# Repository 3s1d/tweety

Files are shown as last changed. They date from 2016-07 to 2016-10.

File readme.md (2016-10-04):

# Skytraxx Tweety
A low-cost audio-only variometer which is fully open hardware/source and Arduino compatible.
It uses a [MS5637](http://www.mouser.com/new/measurement-specialties/measurement-specialties-ms5637/) pressure sensor in combination with [Linear Regression](https://en.wikipedia.org/wiki/Linear_regression) to estimate the current climb rate. All the computations are done on an Atmel [Attiny88](http://www.atmel.com/devices/ATTINY88.aspx). The CR2450 battery should last a whole season...

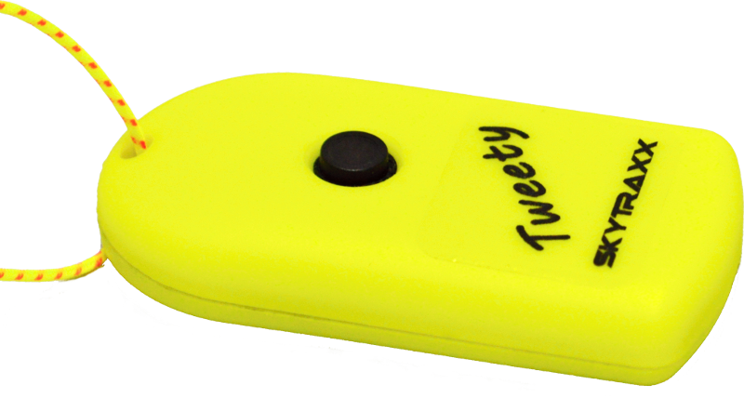
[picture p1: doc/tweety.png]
Tweety


You can build it on your own or buy it in our [shop](https://www.skytraxx.eu/shop?product_id=290) and modify it as you like.

## Operation

### Turn on
Press the button until you here a short beep. Release the button within in 1 second and Tweety turns on. You will here the welcome sound, followed by 0.5 sec pause and the battery state:
- 2 beeps: Battery is good
- 1 beep: Battery is okay
- no beep: You should consider changing the battery

### Turn off
Press the button until you hear the bye sound. Release the button.

### Auto-off
Tweety will shutdown itself if in the past 30 min all climb rate were within -0.8 m/s to 0.8 m/s.

### Configuration
The sink tone can be switched on or off.
Remove the battery. Press and hold the button while re-inserting the coin cell. Release the button. 
- 2 beeps: Sink tone on
- 1 beep: Sink tone off

A short press changes the settings. Use long press (4 sec.) to store the setting and to enter the normal operation mode again.

## Settings
See `climb.h`
- Climb threshold: > 0.3m/s
- Sink threshold: < -2.5m/s
- Averaging interval: 1.5 sec

If you want to change those settings or change the vario tone profile (`piezo.c`), you need to recompile and upload the sources.

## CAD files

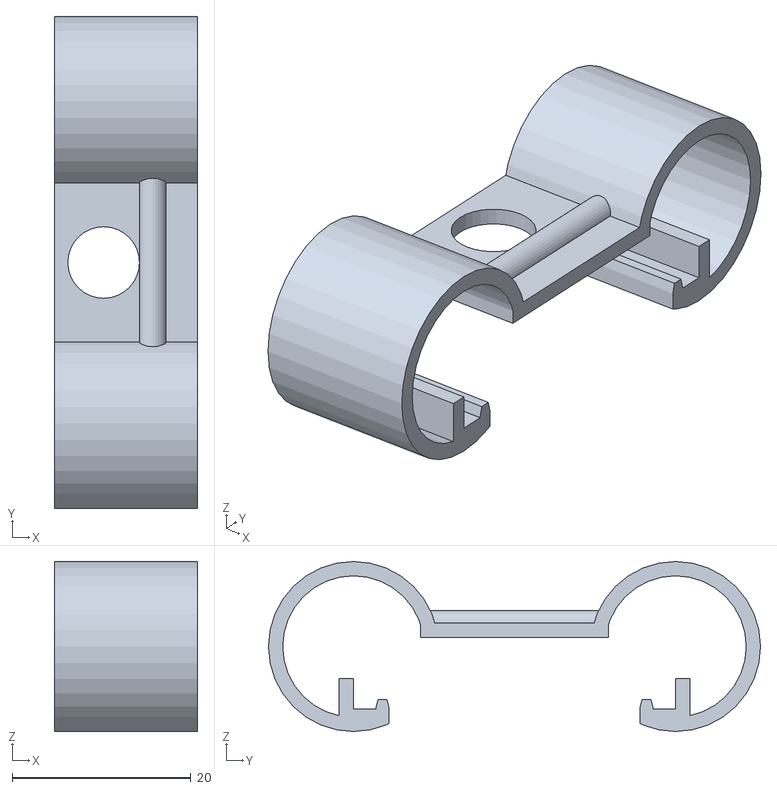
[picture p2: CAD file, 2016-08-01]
mount/clamp.stl
16.0 x 55.0 x 19.0

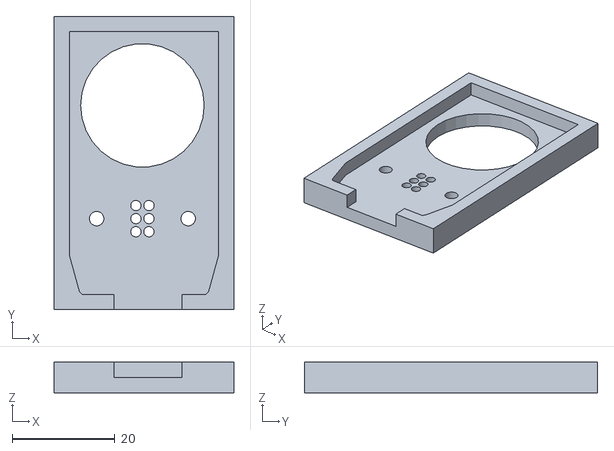
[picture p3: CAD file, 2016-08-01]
mount/base.stl
35.0 x 57.0 x 6.00

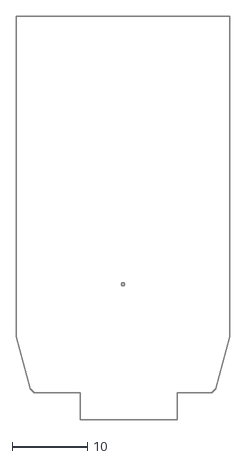
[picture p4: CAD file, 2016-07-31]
mount/tweety.dxf
28.4 x 53.6

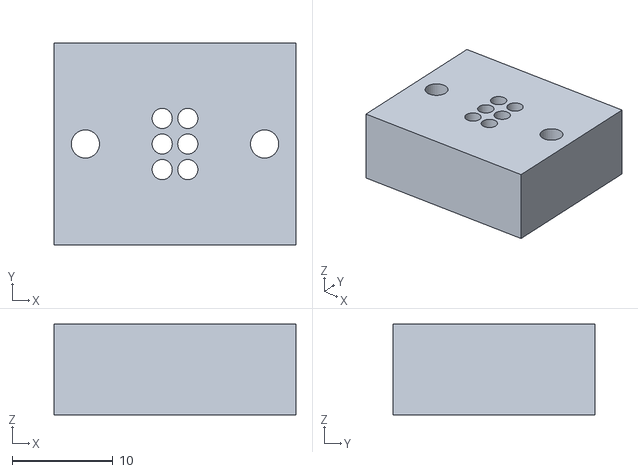
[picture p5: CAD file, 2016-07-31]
mount/base_support.stl
24.0 x 20.0 x 9.00

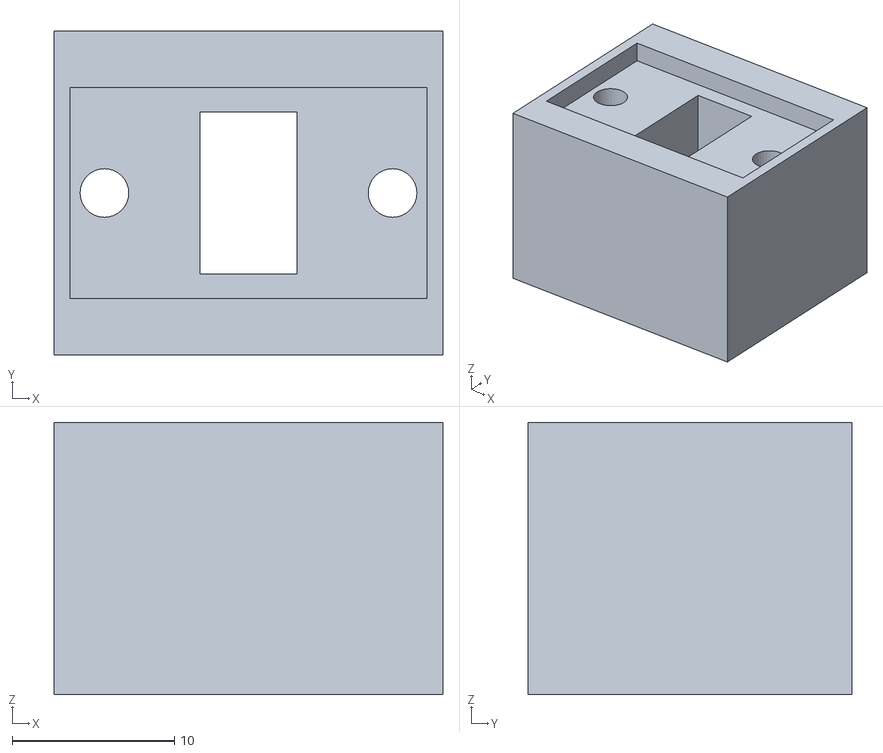
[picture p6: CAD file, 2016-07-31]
mount/base_support2.stl
24.0 x 20.0 x 16.8

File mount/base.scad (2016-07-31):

module pcb(scale = 1)
{
    scale([scale, scale, 1])
    {
        linear_extrude(height = 7)
           import(file = "tweety.dxf");
//        translate([26.3, 20.3, -20])
//            cylinder(r=0.1, h=30);   
    }
}

module isp(v)
{
    translate(v)
    {
        for(i=[-2.54:2.54:2.54])
        {
            translate([1.27,i,-10])
                cylinder(r=1, h=30, $fn=32);
            translate([-1.27,i,-10])
                cylinder(r=1, h=30, $fn=32);
        }
        
        
        translate([1.27 + 2.54*3, 0, -10])
            cylinder(r=2.8/2, h=30, $fn=32);

        translate([-1.27 - 2.54*3, 0, -10])
            cylinder(r=2.8/2, h=30, $fn=32);
    }
}

module clamp_mark(v)
{
    translate(v)
    {
        translate([14,-10,0])
            cube([2,20,1.5]);
        translate([-14-1.5,-10,0])
            cube([2,20,1.5]);        
    }
}

pcb_scale= 1.02;
isp_x = 26.3*pcb_scale;
isp_y = 20.3*pcb_scale;

module top()
{
    difference()
    {
        translate([12.4*pcb_scale-3, 5.9*pcb_scale-3, 0])
        cube([28.4*pcb_scale+2*3,50*pcb_scale+2*3, 6]);

        translate([0,0,3])
           pcb(pcb_scale);

        isp([isp_x, isp_y, 0]);
        clamp_mark([isp_x, isp_y, 0]);
        
        translate([isp_x, isp_y+22, 0])
            cylinder(r=12, h=10);
    }
}

module isp_support(v)
{
    translate(v)
    {
        difference()
        {
            translate([-24/2, -20/2, -9])
                cube([24, 20, 9]);
            isp();
        }
    }
}

module isp_support2(v)
{
    translate(v)
    {
        difference()
        {
            translate([-24/2, -20/2, 0])
                cube([24, 20, 15+1.8]);
 
            isp();           
            translate([-22/2, -13/2, 15])
                cube([22, 13, 1.8]);       
            translate([-6/2, -10/2, 0])
                cube([6, 10, 15+1.8]);
            
            translate([1.27 + 2.54*3, 0, -10])
                cylinder(r=3/2, h=30, $fn=32);

            translate([-1.27 - 2.54*3, 0, -10])
                cylinder(r=3/2, h=30, $fn=32);
        }
    }
}


top();
//isp_support([isp_x, isp_y, 0]);
//isp_support2([isp_x, isp_y, -15-9-1.8]);

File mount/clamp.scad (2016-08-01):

$fn=32;

module teeth(v)
{
    translate([0,-0.75, 0] + v)
    hull()
    {
        translate([0,0.25, 1])
            cube([16,1,0.1]);
        cube([16, 1.5, 0.1]);
    }
}

module clamp_half()
{
    difference()
    {
        union()
        {
            translate([0,28/2,0.4])
                cube([16,5.5, 1.6]);

            translate([0,18,0.4])
                cube([16, 1.6, 5]);

            translate([0,0,10])
                cube([16,10.5, 1.6]);

            teeth([0,29.5/2,2]);
            
            translate([0, 18, 9])
                rotate(90, [0,1,0])
                    difference()
                    {
                        cylinder(r=9.5, h=16);
                        cylinder(r=7.9, h=16);
                        translate([-1, -10, 0])
                            #cube([9,10,18]);
                        translate([-1, -14, 0])
                            #cube([12,10,18]);
                    }
                    
            translate([11, 0, 11.5])
                    rotate(90, [1,0,0])
                        cylinder(r=1.5, h=10);
       }
       translate([16/2-2-0.5, 0,0])
            cylinder(r=4, h=20);
    }
}

mirror([0,1,0])
    clamp_half();
clamp_half();

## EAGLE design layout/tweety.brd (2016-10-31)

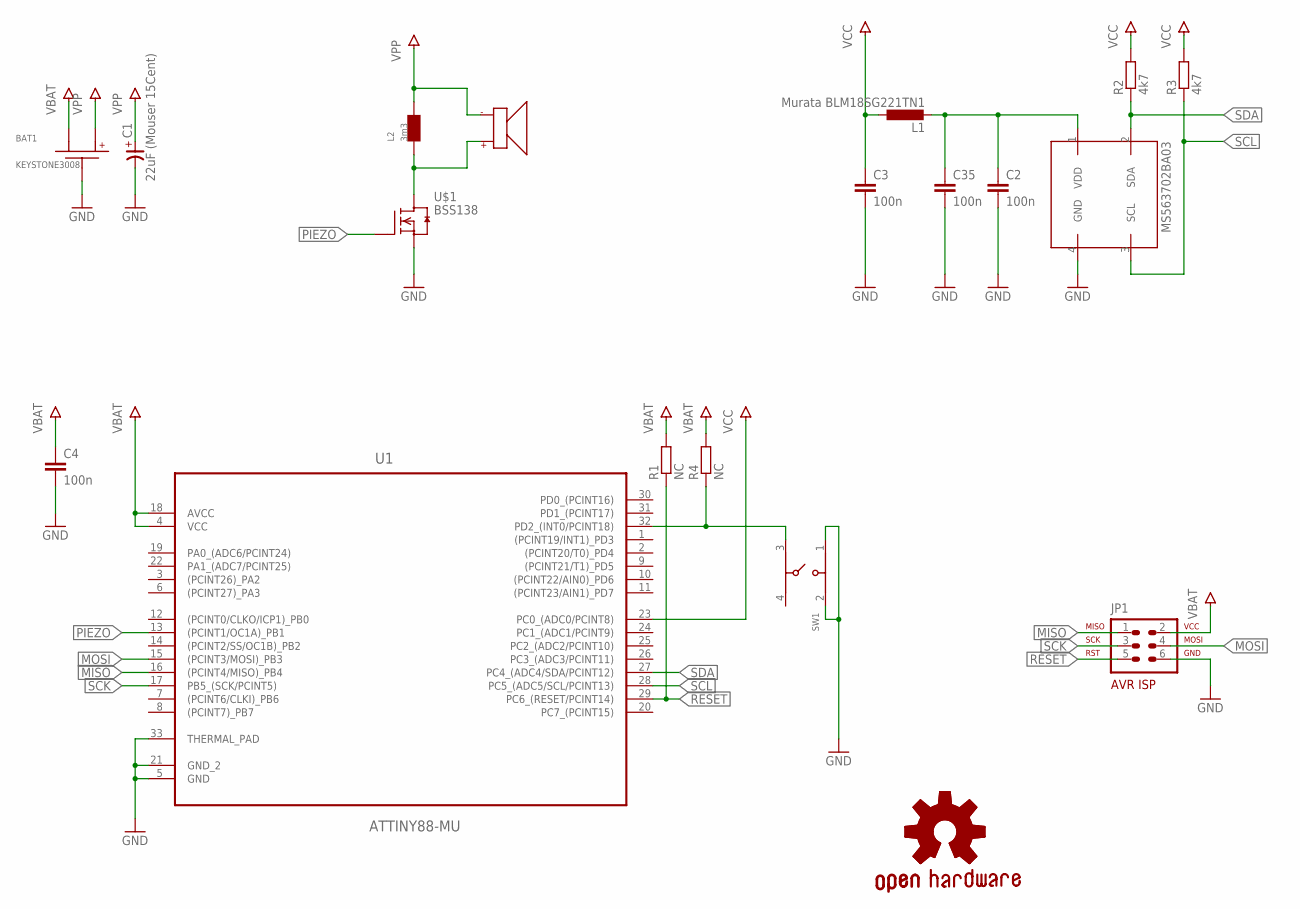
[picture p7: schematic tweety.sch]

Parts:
BAT1: KEYSTONE3008
C1: 22uF (Mouser 15Cent); 3528-21R/T
C2, C3, C4, C35: 100n; C0603
GOLD_ORB_SM1: OSHWLOGO_GOLD_ORB_MED; OSHW1
IC2: MS563702BA03; MS5637
JP1: AVR-ISP-6VERT; AVR-ISP-6
L1: Murata BLM18SG221TN1; L0603
L2: 3m3; SDR0503
P2: PKLCS1212E2400; PKLCS1212
R1, R4: NC; R0603
R2, R3: 4k7; R0603
SW1: 4301X20858X6
U1: ATTINY88-MU; QFN50P500X500X100-33N
U$1: BSS138; SOT23

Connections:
GND: BAT1.N, C1.-, C2.2, C3.2, C4.2, C35.2, IC2.4 (GND), JP1.6, SW1.1, SW1.2, U1.5 (GND), U1.21 (GND_2), U1.33 (THERMAL_PAD), U$1.2 (S)
MISO: JP1.1, U1.16 ((PCINT4/MISO)_PB4)
MOSI: JP1.4, U1.15 ((PCINT3/MOSI)_PB3)
unnamed: C2.1, C35.1, IC2.1 (VDD), L1.2
unnamed: R4.1, SW1.3, U1.32 (PD2_(INT0/PCINT18))
unnamed: L2.P$1, P2.P$+, U$1.3 (D)
PIEZO: U1.13 ((PCINT1/OC1A)_PB1), U$1.1 (G)
RESET: JP1.5, R1.1, U1.29 (PC6_(RESET/PCINT14))
SCK: JP1.3, U1.17 (PB5_(SCK/PCINT5))
SCL: IC2.3 (SCL), R3.1, U1.28 (PC5_(ADC5/SCL/PCINT13))
SDA: IC2.2 (SDA), R2.1, U1.27 (PC4_(ADC4/SDA/PCINT12))
VBAT: BAT1.P$3 (P1), C4.1, JP1.2, R1.2, R4.2, U1.4 (VCC), U1.18 (AVCC)
VCC: C3.1, L1.1, R2.2, R3.2, U1.23 (PC0_(ADC0/PCINT8))
VPP: BAT1.P$4 (P2), C1.+, L2.P$2, P2.P$-

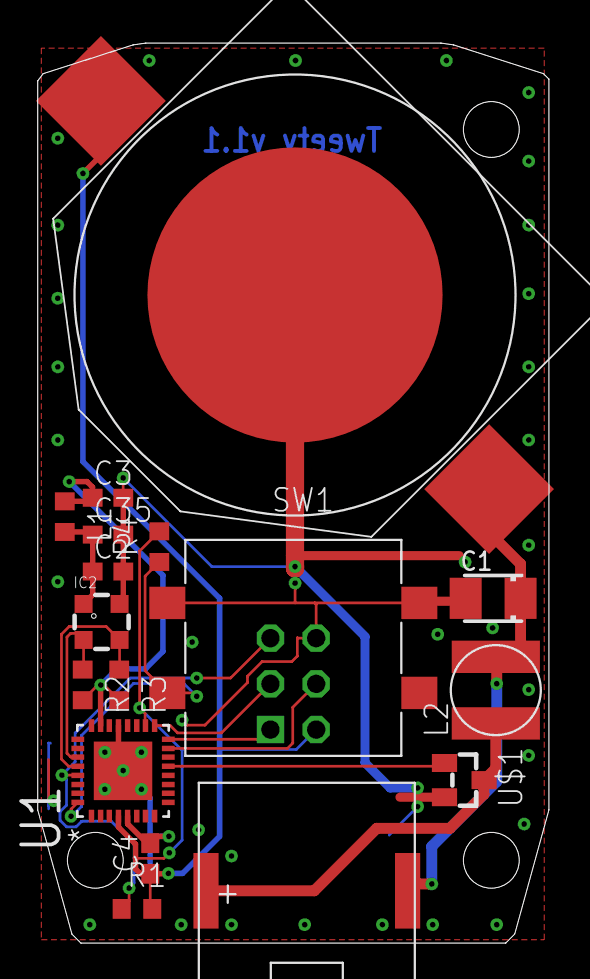
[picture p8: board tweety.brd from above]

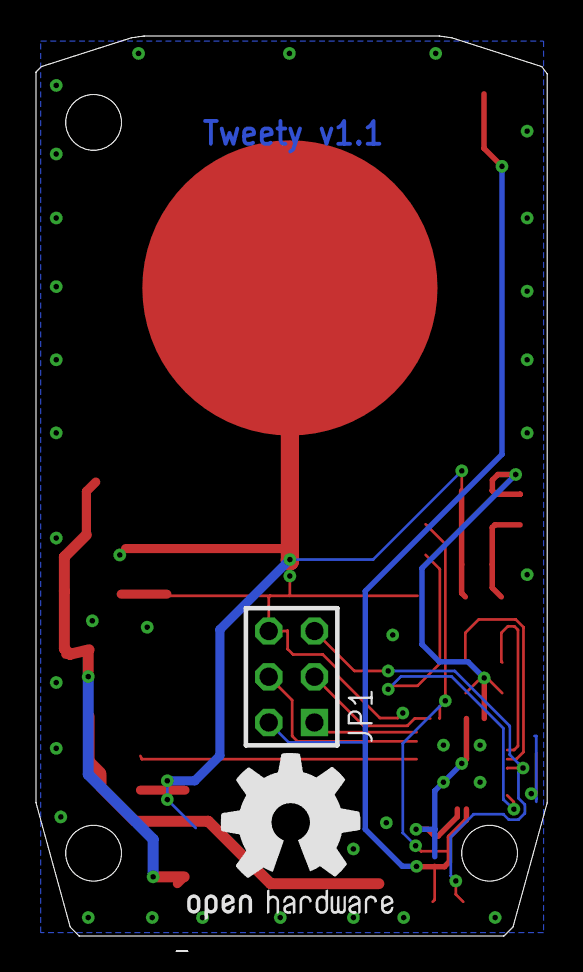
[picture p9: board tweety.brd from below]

Board: 2 copper layers, 28.4 x 50.0 mm, 19 parts (2 on the bottom side), 14 nets.

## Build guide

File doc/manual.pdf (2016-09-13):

⌛2 Sek.

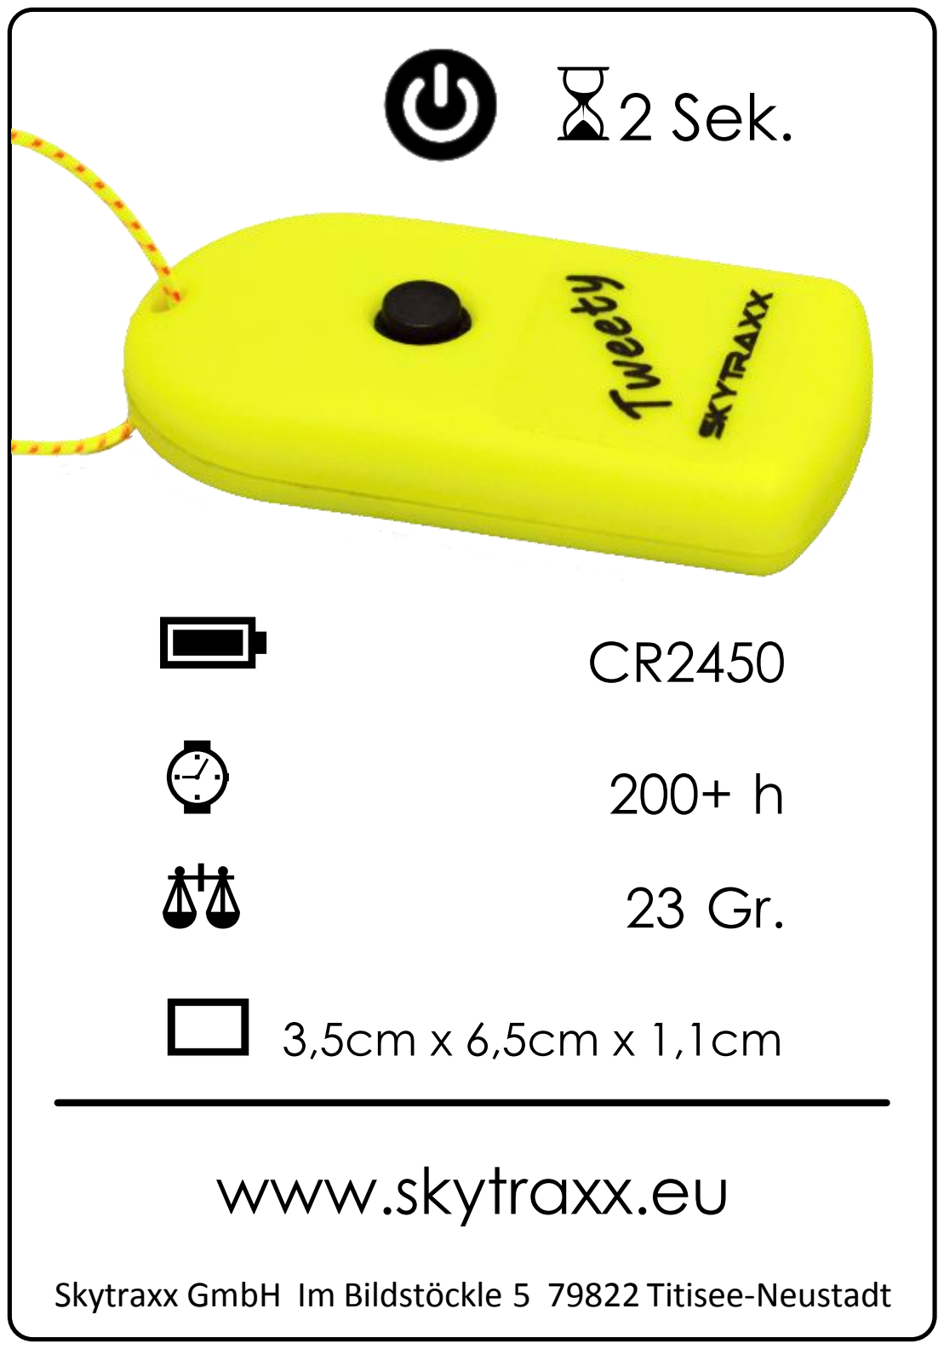
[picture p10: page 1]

🔋 | CR2450
⌚ | 200+ h
⚖ | 23 Gr.

### ▭ 3,5cm x 6,5cm x 1,1cm

## www.skytraxx.eu

Skytraxx GmbH Im Bildstöckle 5 79822 Titisee-Neustadt

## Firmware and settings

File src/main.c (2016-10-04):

/*
 * main.c
 *
 *  Created on: Jun 22, 2016
 *      Author: sid
 */

#include <avr/io.h>
#include <avr/interrupt.h>
#include <avr/power.h>
#include <util/delay.h>

#include "flexport.h"
#include "button.h"
#include "climb.h"
#include "piezo.h"
#include "sleep.h"
#include "main.h"

#include "debug.h"

volatile int t;

int main(void)
{
	/* enable pull-ups for all unused ports (reduces standby power) */
	//note: pins are already set as input
	PORTA = 0x0F;	//all ports
	PORTB = 0xFD;	//all except B,1 (piezo)
	PORTC = 0xCE;	//all except C,0 (ms5637 supply), C,4+5 (TWI)
	PORTD = 0xFF;	//all D,2 requires a pull-up anyway

	/* further reduce power consumption */
	power_spi_disable();
	power_adc_disable();

	/* Switch to 2Mhz */
	CLKPR = (1<<CLKPCE);
#if F_CPU == 2000000UL
	CLKPR = 2;		//div 4 -> 2Mhz
#elif F_CPU == 1000000UL
	//no need to change anything
#else
	#error adjust prescaler.
#endif

	/* Enable interrupts */
	sei();

	/* boot */
	btn_init();
	p_init();
	if(btn_pressed())
		p_config();
	climb_init();

	//debug_put(&p_dosink, 1);

	/* auto off */
	uint16_t idle_time = 0;

	/* button counter; instantaneously go into sleep mode @ power-up */
	uint8_t pressed = UINT8_MAX-1;

	while(1)
	{
		/* update climb rate */
		climb_update();

		/* check for flight condition */
		if((climb_cms < 80) && (climb_cms > -80))
			idle_time++;
		else
			idle_time = 0;

		//debug_put((uint8_t *) &climb_cms, sizeof(uint16_t));

		/* note: values heavily depends on F_CPU */
		/* also switch off about 30 minutes without climb or sink */
		if((pressed > 5) || (idle_time > MAINLOOP_HALFHOUR))
		{
			sleep();

			/* reset enter states */
			pressed = 0;
			idle_time = 0;
		}

		/* handle button */
		if(btn_pressed())
			pressed++;
		else
			pressed = 0;

	}
	return 1;
}

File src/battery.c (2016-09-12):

/*
 * battery.c
 *
 *  Created on: Aug 3, 2016
 *      Author: sid
 */

#include <avr/io.h>
#include <avr/power.h>
#include <util/delay.h>

//#include "debug.h"

uint8_t battery(uint8_t rep)
{
	/* turn on power */
	power_adc_enable();

	/* configure adc */
	ADMUX = _BV(REFS0) | _BV(ADLAR) | 0x0E;			//Vref=VCC | left adjusted | 1.1V channel
	ADCSRA = _BV(ADEN);
	//_delay_ms(1);						//minimum settle time

	/* taking the measurement */
	uint16_t bat = 0;
	for(uint8_t i=0; i<rep; i++)
	{
		_delay_ms(10);
		ADCSRA = _BV(ADEN) | _BV(ADSC) | (3<<ADPS0);		//div 8 (F_CPU=1MHz -> 125kHz Sample freq (recommended: 50-200kHz))
		while(ADCSRA&(1<<ADSC));
		bat += ADCH;
	}
	bat /= rep;

	/* cleanup */
	ADCSRA = 0;
	power_adc_disable();

	//uint8_t u = 2810/bat;
	//debug_put(&u, 1);

	/*
	 * Determine return value
	 *
	 * V = 281/bat
	 * 2V = 140
	 * 3V = 93
	 */
	if(bat <= 112)						// >= 2.5V	50%
		return 2;
	else if(bat<=135)					// >= 2.08V	25%
		return 1;
	else
		return 0;
}

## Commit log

2016-06-11 pcb init
    [tweety.brd, tweety.sch]
2016-06-29 initial layout
    [tweety.brd, tweety.sch]
2016-07-31 mount added
    [base.scad, base.stl, base_support.stl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]
2016-08-01 prior a newtwi driver
2016-08-01 mount revised
    [base.stl, clamp.scad, clamp.stl]
2016-08-02 aquidistant sensor distances
2016-08-02 power on/off
2016-08-02 battery evaluation added
2016-08-05 slightly improved power on feedback
2016-08-08 auto switch off
2016-09-12 very aggressiv battery states
2016-10-03 improved poweron
2016-10-03 new pressur enging, still not working for cold temperatures
2016-10-04 30min power off @ 2Mhz
2016-10-31 layout optimized
    [tweety.brd]

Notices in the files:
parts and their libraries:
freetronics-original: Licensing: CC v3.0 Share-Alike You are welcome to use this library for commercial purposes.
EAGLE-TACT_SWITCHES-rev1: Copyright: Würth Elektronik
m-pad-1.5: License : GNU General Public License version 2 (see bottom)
